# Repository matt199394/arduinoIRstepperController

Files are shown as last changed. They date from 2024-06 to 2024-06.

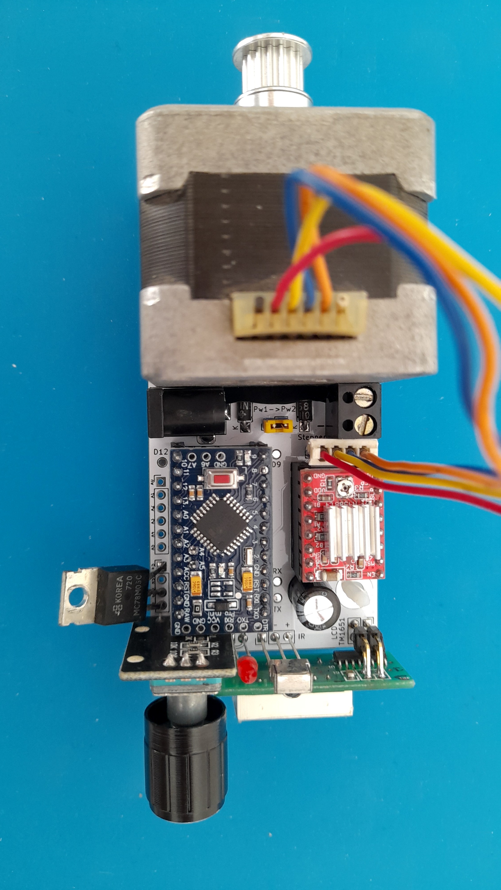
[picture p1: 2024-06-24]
IRstepper2.jpg

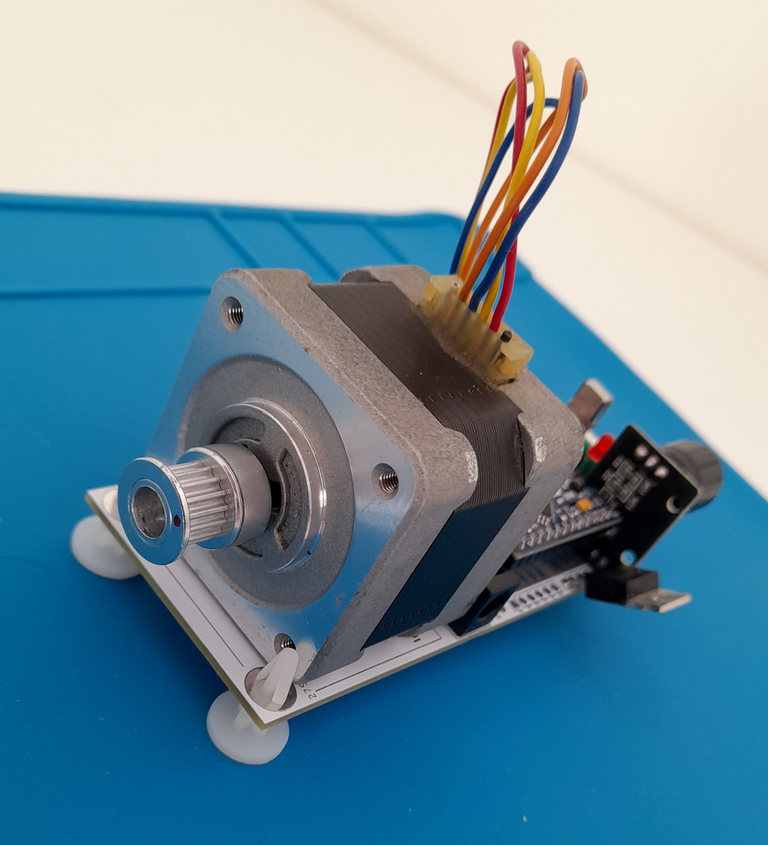
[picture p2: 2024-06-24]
IRstepper3.jpg

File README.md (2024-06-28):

I had the problem to remotely controll the volume of my home-built audio amplifier. For this purpose I created a circuit that allows me to control a stepper motor connected to the amplifier's potentiometer. The stepper motor can be controlled either using the remote control or the rotary encoder. I have to admit it works pretty well :)
I hope it's useful for someone!

Link to a brief video demonstration https://www.youtube.com/watch?v=Ed6FCPk_Rfs

Code update: add timer to disable stepper motor after 5 seconds if no change in stepper position

IRstepper1

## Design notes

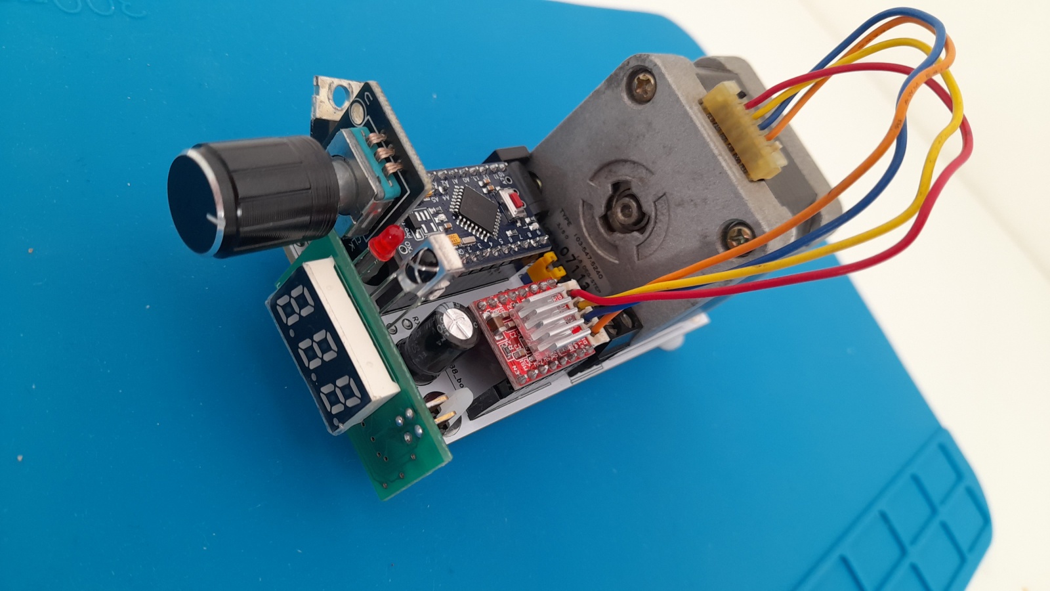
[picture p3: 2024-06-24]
IRstepper1.jpg

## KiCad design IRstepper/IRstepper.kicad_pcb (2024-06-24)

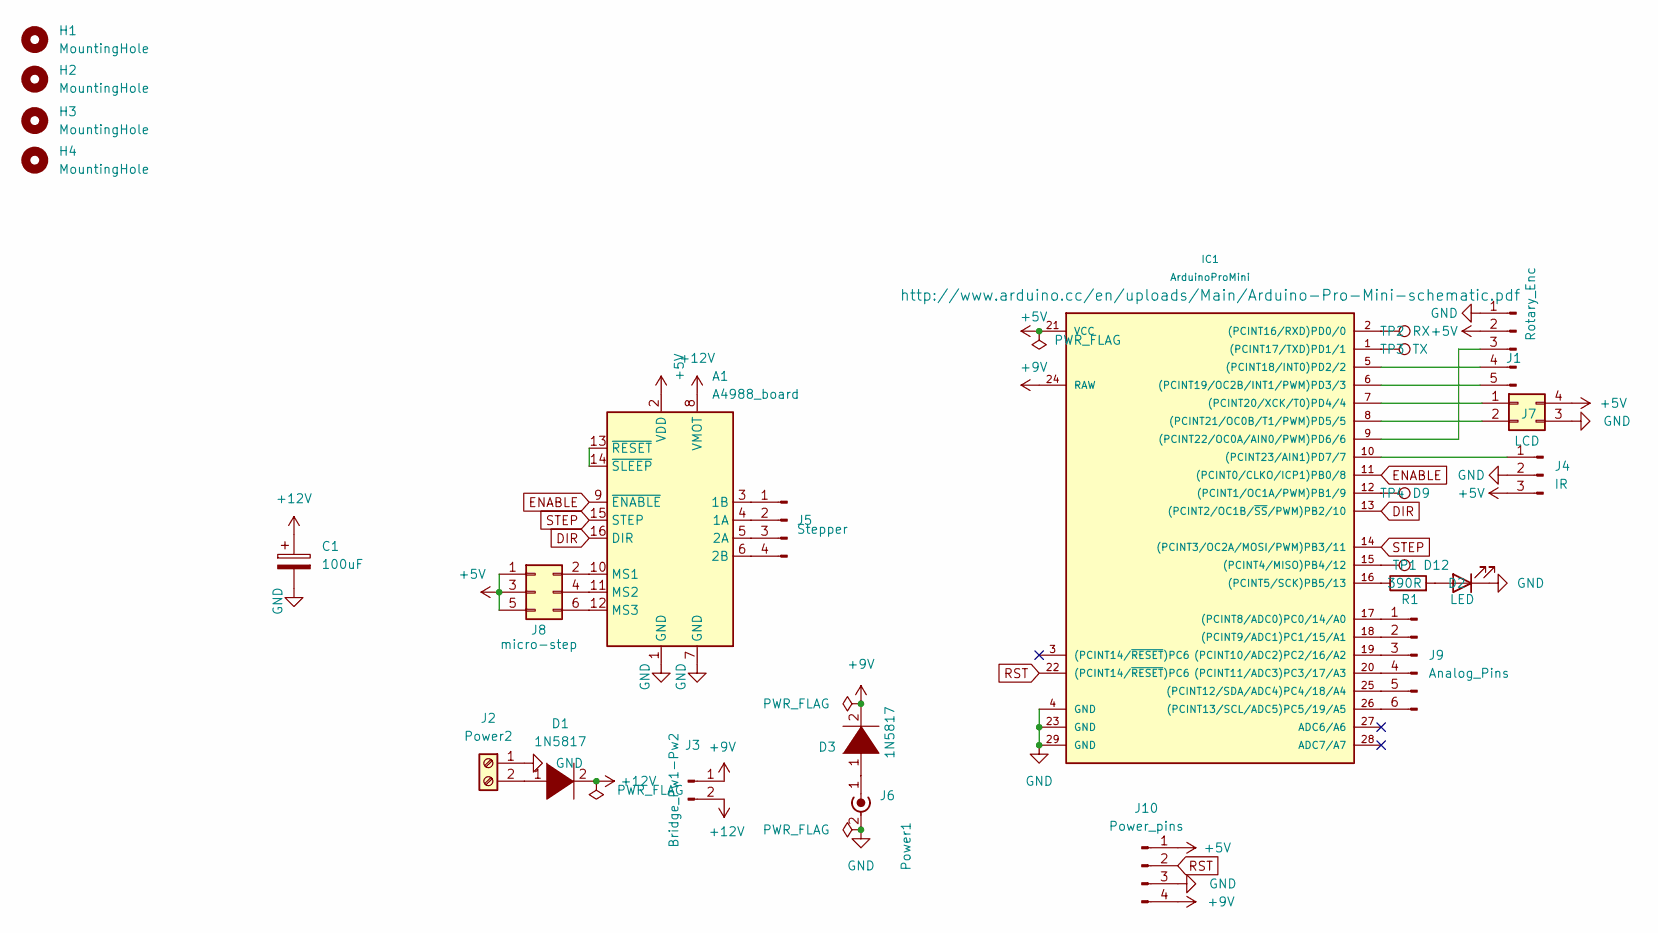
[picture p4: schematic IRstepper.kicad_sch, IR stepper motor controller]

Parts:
A1: A4988_board; Pololu_Breakout-16_15.2x20.3mm
C1: 100uF; CP_Radial_D8.0mm_P3.50mm
D1, D3: 1N5817; D_A-405_P7.62mm_Horizontal
D2: LED; LED_D3.0mm
H1, H2, H3, H4: MountingHole; MountingHole_3.7mm_Pad_TopBottom
IC1: ArduinoProMini; pro_mini
J1: Rotary_Enc; PinHeader_1x05_P2.54mm_Vertical
J2: Power2; TerminalBlock_Phoenix_PT-1,5-2-5.0-H_1x02_P5.00mm_Horizontal
J3: Bridge_Pw1-Pw2; PinHeader_1x02_P2.54mm_Vertical
J4: IR; PinHeader_1x03_P2.54mm_Vertical
J5: Stepper; PinHeader_1x04_P2.54mm_Vertical
J6: Power1; BarrelJack_Horizontal
J7: LCD; PinHeader_2x02_P2.54mm_Vertical
J8: micro-step; PinHeader_2x03_P2.54mm_Vertical
J9: Analog_Pins; PinHeader_1x06_P2.54mm_Vertical
J10: Power_pins; PinHeader_1x04_P2.54mm_Vertical
R1: 390R; R_Axial_DIN0207_L6.3mm_D2.5mm_P7.62mm_Horizontal
TP1: D12; TestPoint_Pad_D1.5mm
TP2: RX; TestPoint_Pad_D1.5mm
TP3: TX; TestPoint_Pad_D1.5mm
TP4: D9; TestPoint_Pad_D1.5mm

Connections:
+5V: A1.2 (VDD), IC1.21 (VCC), J1.2, J4.3, J7.4, J8.1, J8.3, J8.5, J10.1
+9V: D3.2 (A), IC1.24 (RAW), J3.1, J10.4
+12V: A1.8 (VMOT), C1.1, D1.2 (A), J3.2
DIR: A1.16 (DIR), IC1.13 ((PCINT2/OC1B/~SS/PWM)PB2/10)
ENABLE: A1.9 (~ENABLE), IC1.11 ((PCINT0/CLKO/ICP1)PB0/8)
GND: A1.1 (GND), A1.7 (GND), C1.2, D2.1 (K), IC1.4 (GND), IC1.23 (GND), IC1.29 (GND), J1.1, J2.1, J4.2, J6.2 (Ext), J6.3, J7.3, J10.3
unnamed: A1.3 (1B), J5.1
unnamed: A1.4 (1A), J5.2
unnamed: A1.5 (2A), J5.3
unnamed: A1.6 (2B), J5.4
unnamed: A1.10 (MS1), J8.2
unnamed: A1.11 (MS2), J8.4
unnamed: A1.12 (MS3), J8.6
unnamed: A1.13 (~RESET), A1.14 (~SLEEP)
unnamed: D1.1 (K), J2.2
unnamed: D2.2 (A), R1.2
unnamed: D3.1 (K), J6.1 (In)
unnamed: IC1.1 ((PCINT17/TXD)PD1/1), TP3.1
unnamed: IC1.2 ((PCINT16/RXD)PD0/0), TP2.1
unnamed: IC1.5 ((PCINT18/INT0)PD2/2), J1.4
unnamed: IC1.6 ((PCINT19/OC2B/INT1/PWM)PD3/3), J1.5
unnamed: IC1.7 ((PCINT20/XCK/T0)PD4/4), J7.1
unnamed: IC1.8 ((PCINT21/OC0B/T1/PWM)PD5/5), J7.2
unnamed: IC1.9 ((PCINT22/OC0A/AIN0/PWM)PD6/6), J1.3
unnamed: IC1.10 ((PCINT23/AIN1)PD7/7), J4.1
unnamed: IC1.12 ((PCINT1/OC1A/PWM)PB1/9), TP4.1
unnamed: IC1.15 ((PCINT4/MISO)PB4/12), TP1.1
unnamed: IC1.16 ((PCINT5/SCK)PB5/13), R1.1
unnamed: IC1.17 ((PCINT8/ADC0)PC0/14/A0), J9.1
unnamed: IC1.18 ((PCINT9/ADC1)PC1/15/A1), J9.2
unnamed: IC1.19 ((PCINT10/ADC2)PC2/16/A2), J9.3
unnamed: IC1.20 ((PCINT11/ADC3)PC3/17/A3), J9.4
unnamed: IC1.25 ((PCINT12/SDA/ADC4)PC4/18/A4), J9.5
unnamed: IC1.26 ((PCINT13/SCL/ADC5)PC5/19/A5), J9.6
RST: IC1.22 ((PCINT14/~RESET)PC6), J10.2
STEP: A1.15 (STEP), IC1.14 ((PCINT3/OC2A/MOSI/PWM)PB3/11)

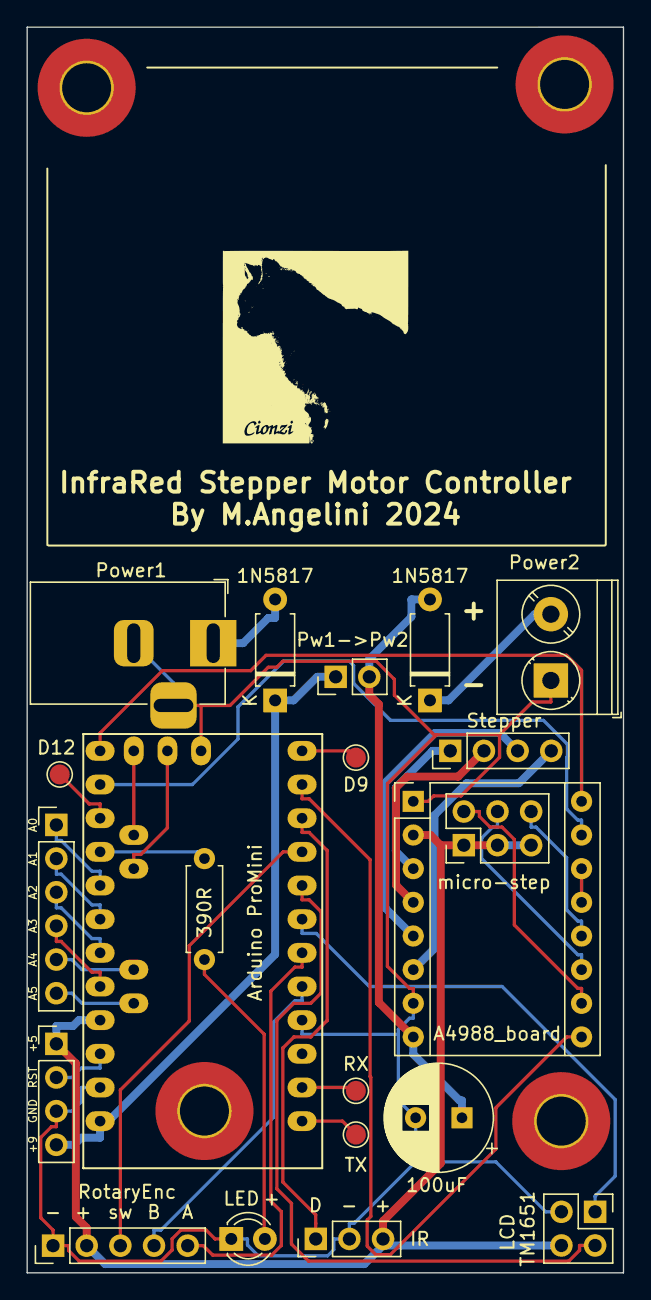
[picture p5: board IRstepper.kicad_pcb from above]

Board: 2 copper layers, 45.0 x 94.0 mm, 26 parts (0 on the bottom side), 36 nets.

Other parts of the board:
 : LOGO; cionzi

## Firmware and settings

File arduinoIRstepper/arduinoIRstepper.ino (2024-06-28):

#include <IRremote.h>
#include "TM1637.h"

#define IR_RECEIVE_PIN 7
#define CLK 4
#define DIO 5
#define encoderPinA  2
#define encoderPinB  3
#define LED 13
#define BUTTON 6


TM1637 tm1637(CLK,DIO);

volatile int pos = 0;
int currentPos = 0;
unsigned long keycode, t1, dt;

const int stepPin = 11;
const int dirPin = 10;
const int enPin = 8;

int stato = HIGH;

void setup() {
  pinMode(LED, OUTPUT);
  pinMode(BUTTON, INPUT_PULLUP);
  pinMode(encoderPinA, INPUT_PULLUP);
  pinMode(encoderPinB, INPUT_PULLUP);

  pinMode(stepPin, OUTPUT);
  pinMode(dirPin, OUTPUT);
  pinMode(enPin, OUTPUT);
  digitalWrite(enPin, HIGH);
  digitalWrite(dirPin, LOW);
  digitalWrite(LED, LOW);

  // encoder pin on interrupt 0 (pin 2)
  attachInterrupt(0, doEncoderA, CHANGE);
  // encoder pin on interrupt 1 (pin 3)
  attachInterrupt(1, doEncoderB, CHANGE);
  
  //Serial.begin(9600); 
  IrReceiver.begin(IR_RECEIVE_PIN);
  //Serial.println("ok");
  
  tm1637.init();
  //BRIGHT_TYPICAL = 2,BRIGHT_DARKEST = 0,BRIGHTEST = 7;
  tm1637.set(BRIGHT_TYPICAL);
  //tm1637.point(POINT_ON);
  shownumber(pos); 
  t1 = 0; 
}


void loop() {
  dt = millis() - t1;
  if (dt >= 5000 && stato == LOW){      
      digitalWrite(enPin, HIGH);
      digitalWrite(LED, LOW);
      stato = !stato;
  }
  
  if (IrReceiver.decode()) {
    keycode = IrReceiver.decodedIRData.command;
    //Serial.println(keycode);
    if ((IrReceiver.decodedIRData.flags & IRDATA_FLAGS_IS_REPEAT)) {
         IrReceiver.resume();
         return;
    }
    IrReceiver.resume();
  }


   if (digitalRead(BUTTON) == LOW) {
      delay(300);
      stato = !stato;
      digitalWrite(enPin, stato);
      digitalWrite(LED, !stato);
      t1 = millis();
      currentPos = pos; 
   }


   if (keycode == 31) {
      delay(300);
      stato = !stato;
      digitalWrite(enPin, stato);
      digitalWrite(LED, !stato);
      keycode = 0;
      t1 = millis();
      currentPos = pos;
      }

   
   if (keycode == 29 && stato == LOW) { 
    pos --;
    if (pos < 0) pos = 0;
    keycode = 0;
      
  }
  
if (keycode == 30 && stato == LOW) { 
    pos ++;
    keycode = 0;
       
  }

if (currentPos != pos && stato == LOW) {
    t1 = millis(); 
    shownumber(pos);
    if (currentPos < pos) {
      
      digitalWrite(dirPin,HIGH);
      digitalWrite(stepPin,HIGH);
      delayMicroseconds(1000);
      digitalWrite(stepPin,LOW);
      delayMicroseconds(1000);
      
      currentPos = pos;
    }
    else if (currentPos > pos && stato == LOW) {
      
      digitalWrite(dirPin,LOW);
      digitalWrite(stepPin,HIGH);
      delayMicroseconds(1000);
      digitalWrite(stepPin,LOW);
      delayMicroseconds(1000);
      
      currentPos = pos;
      }
  }
  
}

void shownumber(int n){

  int d1 = n % 10;
  int d2 = (n/10) % 10;
  int d3 = (n/100) % 10;
  tm1637.display(0,d3);
  tm1637.display(1,d2);
  tm1637.display(2,d1);
}

void doEncoderA() {
  if (stato == LOW) {
  // look for a low-to-high on channel A
  if (digitalRead(encoderPinA) == HIGH) {
    // check channel B to see which way encoder is turning
    if (digitalRead(encoderPinB) == LOW) {
      pos --;         // CW
      if (pos < 0) pos = 0;
    } else {
      pos ++;         // CCW
    }
  } else {// look for a high-to-low on channel A
    if (digitalRead(encoderPinB) == HIGH) {// check channel B to see which way encoder is turning
      pos --;          // CW
      if (pos < 0) pos = 0;
    } else {
      pos ++;          // CCW
    }
  }  
}
}

void doEncoderB() {
  if (stato == LOW) {
  // look for a low-to-high on channel B
  if (digitalRead(encoderPinB) == HIGH) {
    // check channel A to see which way encoder is turning
    if (digitalRead(encoderPinA) == HIGH) {
      pos --;         // CW
      if (pos < 0) pos = 0;
    } else {
      pos ++;         // CCW
    }
  } else { // Look for a high-to-low on channel B
    // check channel B to see which way encoder is turning
    if (digitalRead(encoderPinA) == LOW) {
      pos --;          // CW
      if (pos < 0) pos = 0;
    } else {
      pos ++;          // CCW
    }
  }
}
}
